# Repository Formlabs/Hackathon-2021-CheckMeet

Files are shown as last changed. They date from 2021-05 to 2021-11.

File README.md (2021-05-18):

CheckMeet
=========

The warning that you are on a meeting or even your camera is on.

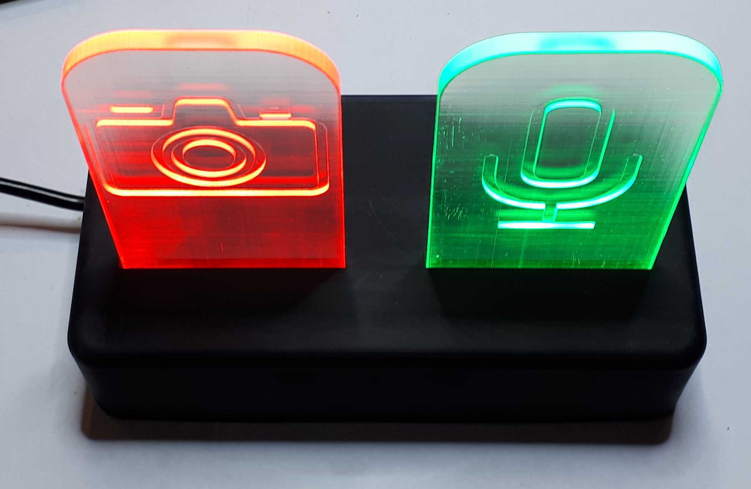
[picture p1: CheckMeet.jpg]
CheckMeet


The idea
--------

Working from home can be difficult, the family may not know when we are on a meeting and the camera or microphone is on.
Let’s help them with a sign!

But since you are at your table and they can be in the other room this sign must be there. With the help of WiFi it is not a problem.

The device
----------

Heart of this project is a NodeMCU-ESP8266 board. It connects to your home WiFi and waiting information from your computer.
When your microphone or camera is on it lights up the appropriate LEDs. When your computer is off it will switch off the LEDs, so you can still sleep well during night.

The SW
------

For the communication you need to run a small SW on your computer. It is written in Python and has a notification icon to show that it is running.
Currently you have to check the device IP manually but we have plans to improve that in the future.

Quick start
-----------

See quick start guide [here](doc/QuickStart.md)

Acknowledgment
--------------

Original idea is taken from this project:
https://github.com/tlevis/S.H.I.E.L.D

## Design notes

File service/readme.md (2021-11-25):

# Service

TODO: write the section explaining that it's the script that sends the camera/mic status to the device and how to start it etc.

## Quick start guide

See Quick start guide [here](../QuickStart.md)

## For developers

### Dependencies

To install the dependencies of the project, you have two options.

#### Option 1: requirements.txt

We provide a generated `requirements.txt` that describes the necessary packages to develop and run the project.

Activate your favorite virtual python environment or call it with your system-wide python:

```
pip install -r requirements.txt
```

#### Option 2: Pipfile

##### Prerequisites

`pipenv` (https://pipenv.pypa.io/en/latest/) is a tool that can generate virtual python environments per project directory and can manage the project's dependencies.

You can install it with `pip` (https://pypi.org/project/pipenv/).

In short, for Windows:

```
pip install pipenv
```

For macOS, it's also available via `brew`:

```
brew install pipenv
```

For Linux, your package manager most probably has it, see https://pypi.org/project/pipenv/.

##### Setup environment

Once you have `pipenv` installed, in this folder, you can call

```
pipenv install
```

It will create the virtual python environment and install the dependencies for you.

You can activate the virtual python environment by `pipenv shell`.

### Launch the service

You can use the following command to launch the service in your virtual environment (replace `<DEVICE_IP>` with the IP address of your device):

```
python launch_service.py <DEVICE_IP>
```

If you're using `pipenv`, you can launch the service without explicitly activating the environment this way:

```
pipenv run python launch_service.py <DEVICE_IP>
```

### Source files

There are two main programs in this directory: `service.py` (checking the user's camera & microphone status, and sending it to the device) and the `emulator.py` (simulating a device by listening on the same port, and printing the incoming packets). Some common code among these two is stored in `common.py`.

`launch_service.py` and `launch_emulator.py` are lightweight wrappers checking if the user's using the required python version, then calling their respective implementation files.

The platform-specific parts of the code (checking whether the camera/microphone is turned on, showing notifications) are implemented in the `driver_*.py` files:
- `driver_win.py`, `driver_mac.py` and `driver_linux.py` implement the real features
- `driver_auto.py` checks the current platform, and loads one of the platform-specific drivers accordingly
- `driver_fake.py` can be used during testing when no real driver is implemented for a platform: it returns the values found in `fake.json`

### MacOS code signing

The code signing key should be generated using the `Keychain Access` application of Mac.
Currently we are operating with a *Self Signed Root* *Code Signing* certificate with overridden defaults to extend its expiration to ten years.
To export it properly as .p12 *BOTH the certificate AND the private key* need to be selected.
Use a strong password to save the certificate like generated by `pwgen 20`.
The following github action secrets need to be updated:

- `MACOS_CERTIFICATE`: `base64 ~/Desktop/Certificates.p12 | pbcopy`
- `MACOS_CERTIFICATE_PASSWORD`: the password used to save the certificate

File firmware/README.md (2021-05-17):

## Setting up arduino for development

https://www.instructables.com/Steps-to-Setup-Arduino-IDE-for-NODEMCU-ESP8266-WiF/

Libraries to install:
- [WiFiManager by tzapu,tablatronix](https://github.com/tzapu/WiFiManager)
- [FastLED by Daniel Garcia](http://fastled.io)
- [TM1637 by Avishay Orpaz](https://github.com/avishorp/TM1637)

The bootloaders seem to communicate using 74880 baud so we use it as well.

On Mac / Big Sur I needed this:

https://www.tweaking4all.com/forum/postid/3176/

On Windows driver is needed:

https://github.com/nodemcu/nodemcu-devkit/blob/master/Drivers/CH341SER_WINDOWS.zip

Note: board is NodeMCU v0.9

## Running the unit tests

For Mac (and probably Linux) run the helper script `test.sh`.

## Other software components (no need to install)

- UDP receiver: https://arduino-esp8266.readthedocs.io/en/latest/esp8266wifi/udp-examples.html
- https://arduinojson.org/

## Wiring instructions

See [here](../doc/BuildTheDevice.md)

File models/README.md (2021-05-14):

## Printable models

BasePlate.stl and House.stl models should be printed from black or
some dark material, because LED may light through them.

ClearCamera.stl and ClearMic.stl should be printed from clear, I suggest 50micron.

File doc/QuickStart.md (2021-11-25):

# Quick start guide

To use this software, you need two components:
- a _device_ with an installed _firmware_, connected to your Wi-Fi network
- your computer(s) running the _service_

## Device

### Build the device

If you don't already have a physical device, you need to build it. Find instructions [here](BuildTheDevice.md)

### Install latest firmware on device

You have two options: you can either download the firmware from our [Releases] page, then upload it to your device, or you can compile it manually.

Independently of which approach you pick, you need to connect your device through a microUSB cable.
Make sure the cable is not a charge only one and it has data wires!
When the device is connected to the computer, a new serial device will come up in the operating system, something like

- `/dev/cu.usbserial-143330` for MacOS,
- `COM4` for Windows (you need to install [this driver](https://github.com/nodemcu/nodemcu-devkit/blob/master/Drivers/CH341SER_WINDOWS.zip) first, then check for a new "Port" device in Device Manager), or
- `/dev/ttyUSB0` for Linux.

This will be referred to `<PORT>` below.

#### Option 1: Download firmware from Releases page

1. Download `firmware-vXXX.ino.nodemcu.bin` from the [Releases] page.
2. Install esptool by running `pip3 install esptool`
3. Run the following command (replacing `<PORT>` and `<FIRMWARE_FILE_NAME>` with the appropriate values):

```
esptool.py --chip esp8266 --port <PORT> --baud 115200 --before default_reset --after hard_reset write_flash 0x0 <FIRMWARE_FILE_NAME>
```

#### Option 2: Compile firmware manually

1. Set up the development environment as described in [this document](../firmware/README.md).
2. Open `firmware.ino` in the Arduino IDE.
3. `Menu` / `Sketch` / `Upload`

### Connect the device to your Wi-Fi network

An unconfigured device always boot up acting as a Wi-Fi access point with a name like `CheckMeet_ABCDEF`.

1. Connect to the device via Wi-Fi, a cellphone can be used for this.
2. The device will present a captive portal where the Wi-Fi can be configured.
   If it doesn't pop up for some reason, navigate to http://192.168.4.1/.
3. Click `Configure WiFi`
4. Pick the Wi-Fi access point the device needs to connect to and enter the password.

### Find out the IP address of your device

You need to check your router's status page to find out the IP address of your device.

## Service

You have two options: you can either download the service binary from our [Releases] page, or you can run it from code.

### Option 1: Download service from Releases page

#### Windows

Download `CheckMeet-Windows-XXX.exe` from the [Releases] page. (`CheckMeet-Windows-console-XXX.exe` is for experts)

You can start the downloaded .exe by simply double-clicking on it, it will ask for the device's IP address.

Alternatively, you can start it from a console window, and provide the device IP as a command line argument (replace `<DEVICE_IP>` with your device's IP address):

```
CheckMeet-Windows-XXX.exe <DEVICE_IP>
```

#### MacOS

Download `CheckMeet-Mac-XXX.dmg` from the [Releases] page.

When starting the downloaded application a warning will be displayed telling "CheckMeet.app can't be opened because Apple cannot check it for malicious software".
This warning cannot be skipped first time but it can be silenced afterwards if you right-click on the application icon and select Open there.
CheckMeet will ask for the device's IP address when it's successfully started.

#### Ubuntu

1. Download `CheckMeet-Ubuntu-XXX` from the [Releases] page.
2. Make the file executable by issuing `chmod +x CheckMeet-Ubuntu-XXX`.
3. Run the file either from the command line or by double-clicking on it, it will ask for the device's IP address.

Note: You may need to install the package `libxcb-xinerama0` to make the program work.

### Option 2: Run it from source

#### Get the source

You can either clone this repository, or grab it as a .zip file from [here](https://github.com/Formlabs/Hackathon-2021-CheckMeet/archive/refs/heads/master.zip).

#### Install pipenv

The service uses `pipenv` to manage dependencies. You can install it using `pip`:

```
pip install pipenv
```

For macOS, it's also available via `brew`:

```
brew install pipenv
```

For Linux, your package manager most probably has it, see https://pypi.org/project/pipenv/.

#### Launch the service

Open a command line in the `service` directory, then use the following command to launch the service (replace `<DEVICE_IP>` with the IP address of your device):

```
pipenv run python launch_service.py <DEVICE_IP>
```

Congratulations, your status is now displayed on the device!

[Releases]: https://github.com/Formlabs/Hackathon-2021-CheckMeet/releases

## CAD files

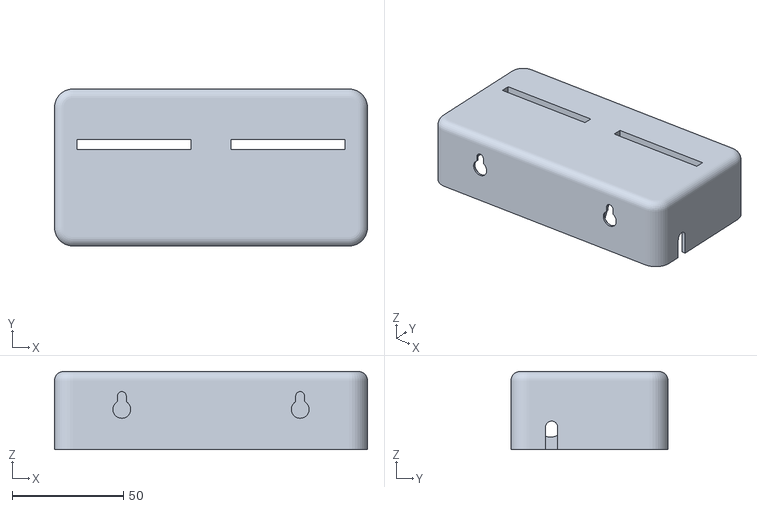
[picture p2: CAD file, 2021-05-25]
models/House_Button_SmallDisplay.stl
140.4 x 70.4 x 35.0

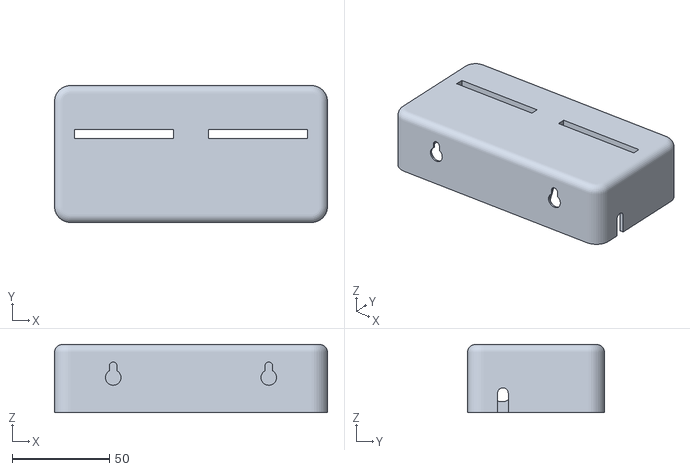
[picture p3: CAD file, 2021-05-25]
models/House_Button_BigDisplay.stl
140.4 x 70.4 x 35.0

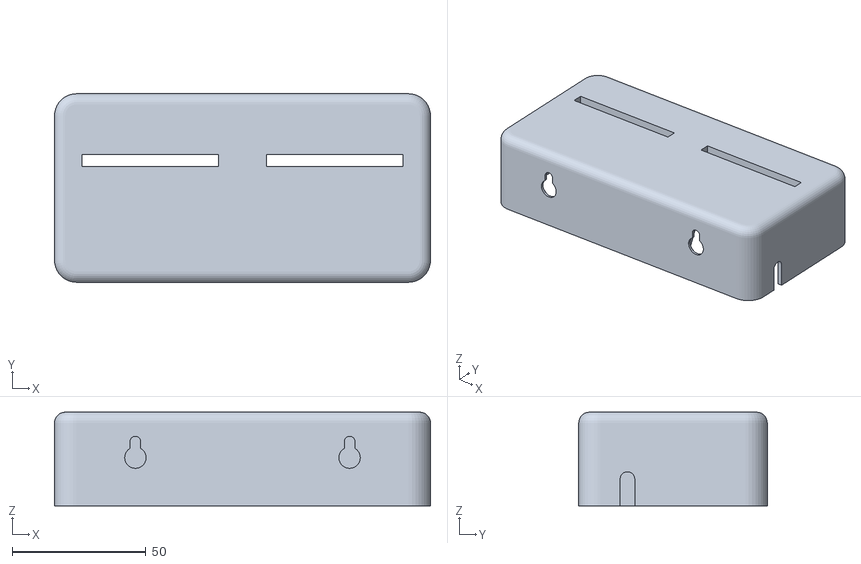
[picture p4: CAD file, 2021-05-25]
models/House.stl
140.4 x 70.4 x 35.0

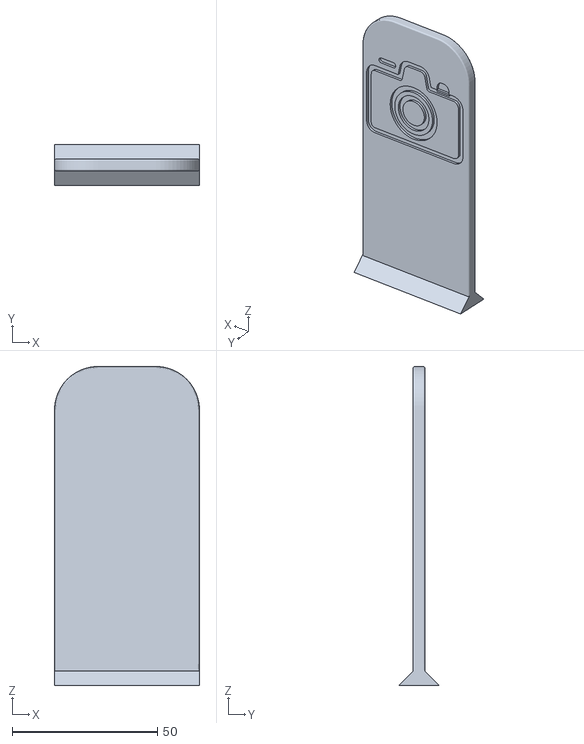
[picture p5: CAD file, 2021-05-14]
models/ClearCamera.stl
50.0 x 14.0 x 110.0

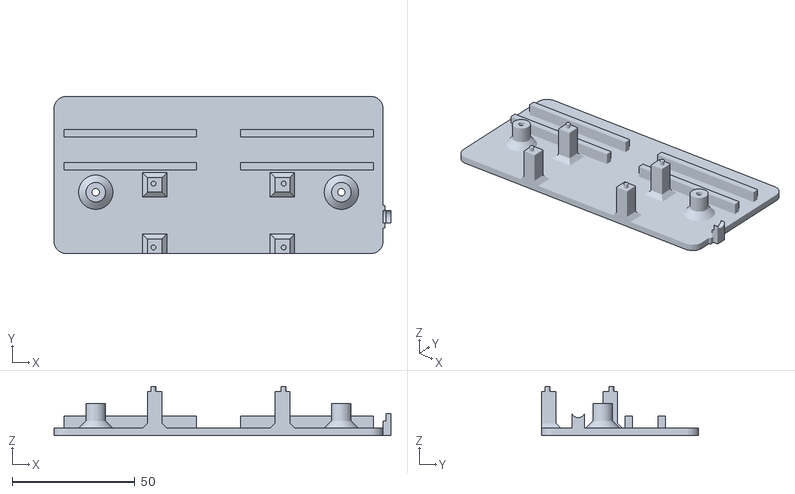
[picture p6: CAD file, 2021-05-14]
models/BasePlate.stl
137.2 x 64.0 x 20.0

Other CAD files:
models/House_Button.stl
models/ClearMic.stl

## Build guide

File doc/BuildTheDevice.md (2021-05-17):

TODO

## Wiring

| Peripheral pin | NodeMCU pin | Note |
|---|---|---|
| LED strip GND  | G | |
| LED strip 5V | VU | |
| LED strip DIN  | D2 | via a 200-500 ohm resistor |
| 7seg 5V | VU | |
| 7seg GND | G | |
| 7seg DIO | D5 | |
| 7seg CLK | D6 | |
| Button pin 1 | G | |
| Button pin 2 | D3 | same as on board FLASH btn |

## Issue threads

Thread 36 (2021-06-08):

Get rid of FastLED

LaszloAshinFormlabs, 2021-06-08:
FastLED emits warnings already.
When we upgrade to esp8266 platform 3.0.0 it will emit a lot of new warnings as well and cause LED flickering.
Maybe a new version of FastLED will solve this but the code doesn't seem to be very portable.

Also FastLED doesn't support using esp8266's I2S capability -- but that would also need some change in the wiring.

https://github.com/Formlabs/Hackathon-2021-CheckMeet/pull/29#discussion_r647108717

@petamas @balintfodor @PeterVarhegyiF thoughts?

- Do you think we can change the wiring? LED strip data input should go to NodeMCU's `RX` instead of `D2` (still needs to be tested, I am asking theoretically)
- Do you agree we should drop FastLED?

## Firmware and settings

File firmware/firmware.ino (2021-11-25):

#include <WiFiManager.h>
#include <WiFiUdp.h>

#define FASTLED_ESP8266_RAW_PIN_ORDER
#include <FastLED.h>

#include <ESP8266mDNS.h>
#include <TM1637Display.h>

#include "lib_firmware.h"
#include "serialnames.h"

class Device : public I_Device {
  static constexpr int NUM_LEDS = 6;
  CRGB leds[NUM_LEDS];
  static constexpr auto PIN_LEDS = D2;

  static constexpr int DISPLAY_CLK = D6;
  static constexpr int DISPLAY_DIO = D5;
  TM1637Display display{DISPLAY_CLK, DISPLAY_DIO};

  CRGB decode(Color color) {
    switch(color) {
      case Color::On: return CRGB::Red;
      case Color::Off: return CRGB::Green;
      case Color::Standby: return CRGB::Black;
      case Color::Initializing: return CRGB::Yellow;
      default: return CRGB::Black;
    }
  }

  public:
    Device() {
      Serial.begin(74880);
      FastLED.addLeds<NEOPIXEL, PIN_LEDS>(leds, NUM_LEDS);
      display.setBrightness(0x0a); //set the diplay to maximum brightness
    }

    virtual void log(StringView message) override {
      Serial.printf("%.*s", static_cast<int>(message.size()), message.data());
    }

    virtual void setMicrophoneLeds(Color color) override {
      leds[0] = leds[1] = leds[2] = decode(color);
      FastLED.show();
    }

    virtual void setWebcamLeds(Color color) override {
      leds[3] = leds[4] = leds[5] = decode(color);
      FastLED.show();
    }

    virtual void displayNumber(int number) override {
      if (number) {
        display.showNumberDec(number);
      } else {
        display.clear();
      }
    }
};

WiFiUDP Udp;
static const uint16_t localUdpPort = 26999;

constexpr auto PIN_BUTTON = D3;
static bool button = true;

std::unique_ptr<I_Device> device;
std::unique_ptr<I_Firmware> firmware;

void setup() {
  device = make_unique<Device>();
  firmware = make_unique<Firmware>(*device);

  const auto hostname = computeNameForId(ESP.getChipId());
  WiFi.mode(WIFI_STA);
  WiFi.hostname(hostname.c_str());
  if (WiFiManager().autoConnect(fmt("CheckMeet_%06X", ESP.getChipId()).c_str())) {
    Serial.println("Connected \\o/");
  } else {
    Serial.println("Failed to connect :(");
  }
  Udp.begin(localUdpPort);
  Serial.printf("Now listening at IP %s, UDP port %d\n", WiFi.localIP().toString().c_str(), localUdpPort);
  pinMode(PIN_BUTTON, INPUT_PULLUP);
  if (MDNS.begin(hostname.c_str())) {
    MDNS.addService("checkmeet", "udp", localUdpPort);
  }
}

void loop() {
  Timestamp now = millis();

  firmware->loopStarted(now);

  MDNS.update();

  int packetSize = Udp.parsePacket();
  if (packetSize) {
    // receive incoming UDP packets
    Serial.printf("Received %d bytes from %s, port %d\n", packetSize, Udp.remoteIP().toString().c_str(), Udp.remotePort());
    char incomingPacket[255];
    int len = Udp.read(incomingPacket, 255);
    if (len > 0) {
      incomingPacket[len] = 0;
    }
    firmware->udpReceived(now, StringView(incomingPacket, len));

    // send back a reply, to the IP address and port we got the packet from
    //Udp.beginPacket(Udp.remoteIP(), Udp.remotePort());
    //Udp.write(replyPacket);
    //Udp.endPacket();
  }

  {
    const auto newButton = digitalRead(PIN_BUTTON);
    if (newButton != button) {
      button = newButton;
      Serial.printf("button goes %d\n", button);
    }
  }
  firmware->loopEnded(now);
}

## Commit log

2021-05-13 Windows driver info
2021-05-13 Add fake driver
2021-05-13 Extract driver selection from service
2021-05-13 Drive the led strip
2021-05-13 Implement mac driver
2021-05-13 Handle input button
2021-05-14 Adding first version of models
    [BasePlate.stl, House.stl]
2021-05-14 Second version of the models
    [BasePlate.stl, House.stl]
2021-05-14 Model LED holder correction
    [BasePlate.stl]
2021-05-14 Adding clear models
    [ClearCamera.stl, ClearMic.stl]
2021-05-15 Test the LED switch-off when clients are inactive
2021-05-15 Switch off lights when no sender activity
    Remove trailing whitespaces. Fixes #9.
    [firmware.ino]
2021-05-15 Cleanup switch-off test
2021-05-15 Remove generated Pipfile.lock
    As it lists pyobjc-framework-quartz without system marker and causes problems on the different platforms.
2021-05-15 Use common.log instead of print
2021-05-15 Cut down on repetition in drivers
2021-05-15 Fix "notification is blocking thread" issue
    Also, this way it's Qt-compatible
2021-05-15 Move LEDs and display to 5V instead of 3V
    This seems to be more stable, although we need to solder two
    wires to one pin on the NodeMCU.
2021-05-17 Move wiring info to its own file
2021-05-17 Fix Darwin filter in req.txt
2021-05-17 Fix more Darwin filter in req.txt
2021-05-18 Add python script to compute serial names
    Each device will have a nice readable name which is easier to remember
    than a six digit hexadecimal number. This script prototypes the approach.
2021-05-18 Query device IP if started without parameters
2021-05-18 Add missing notes on using the dmg file
    Also fix the missing linux device file name.
2021-05-25 New strengthen models and options for 7 segment displays
    [House.stl, House_Button.stl, House_Button_BigDisplay.stl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]
